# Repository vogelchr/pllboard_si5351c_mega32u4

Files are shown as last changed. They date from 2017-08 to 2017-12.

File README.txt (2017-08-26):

Si5351C PLL + ATmega32U4 PLL / OCXO-Control / Clock Generator

A PCB to provide a Si5351C clock generator IC with power via USB
and also have a ATmega32U4 control it.

The PLL chip can be provided two clocks:

 (1) standalone XTAL for Si5351C
      -> populate XT2

 (2a) external reference input (X8)
     (top right SMA connector when looking at top layer of PCB)

     -> Populate R18 (termination for SMA X8)
     -> Populate R27 (connects X8 with J3, Pin7)
     -> Populate R21, R22 (voltage divider to match Si5351C clkin voltage)

 (2b) quartz (TCXO, OCXO) oscillator connected to J3

     -> Populate R21, R22 (voltage divider to match Si5351C clkin voltage)
     -> A MCP47x6 DAC can be populated to provide a control voltage

If the clock (2a/2b) should be disciplined, this can be achieved
by having the ATmega32U4 determine the clock phase.

 (1) have a 1PPS input on the reference input (X8)

     -> Populate R17, R18 (termination, series resistor) for the
        atmega32u4 comparator input

     Then have the Si5351C output a suitable frequency to the atmega32u4
     on clock output 3, and...

     -> pouplate R25 to feed the external timer clock input T0,
        which has a maximum frequency of clkIO/2

          or

     -> populate R26, R20 and feed this frequency to the atmega32u4
        as the system clock. in this case, the otp memory of the
        Si5351C will have to be programmed so that it starts up
        with the clk3 active, and care must be taken not to turn
        off this clock, or the atmega32u4 will stop operating

     This way the ATmega32U4 can measure the clock phase of the 1PPS.

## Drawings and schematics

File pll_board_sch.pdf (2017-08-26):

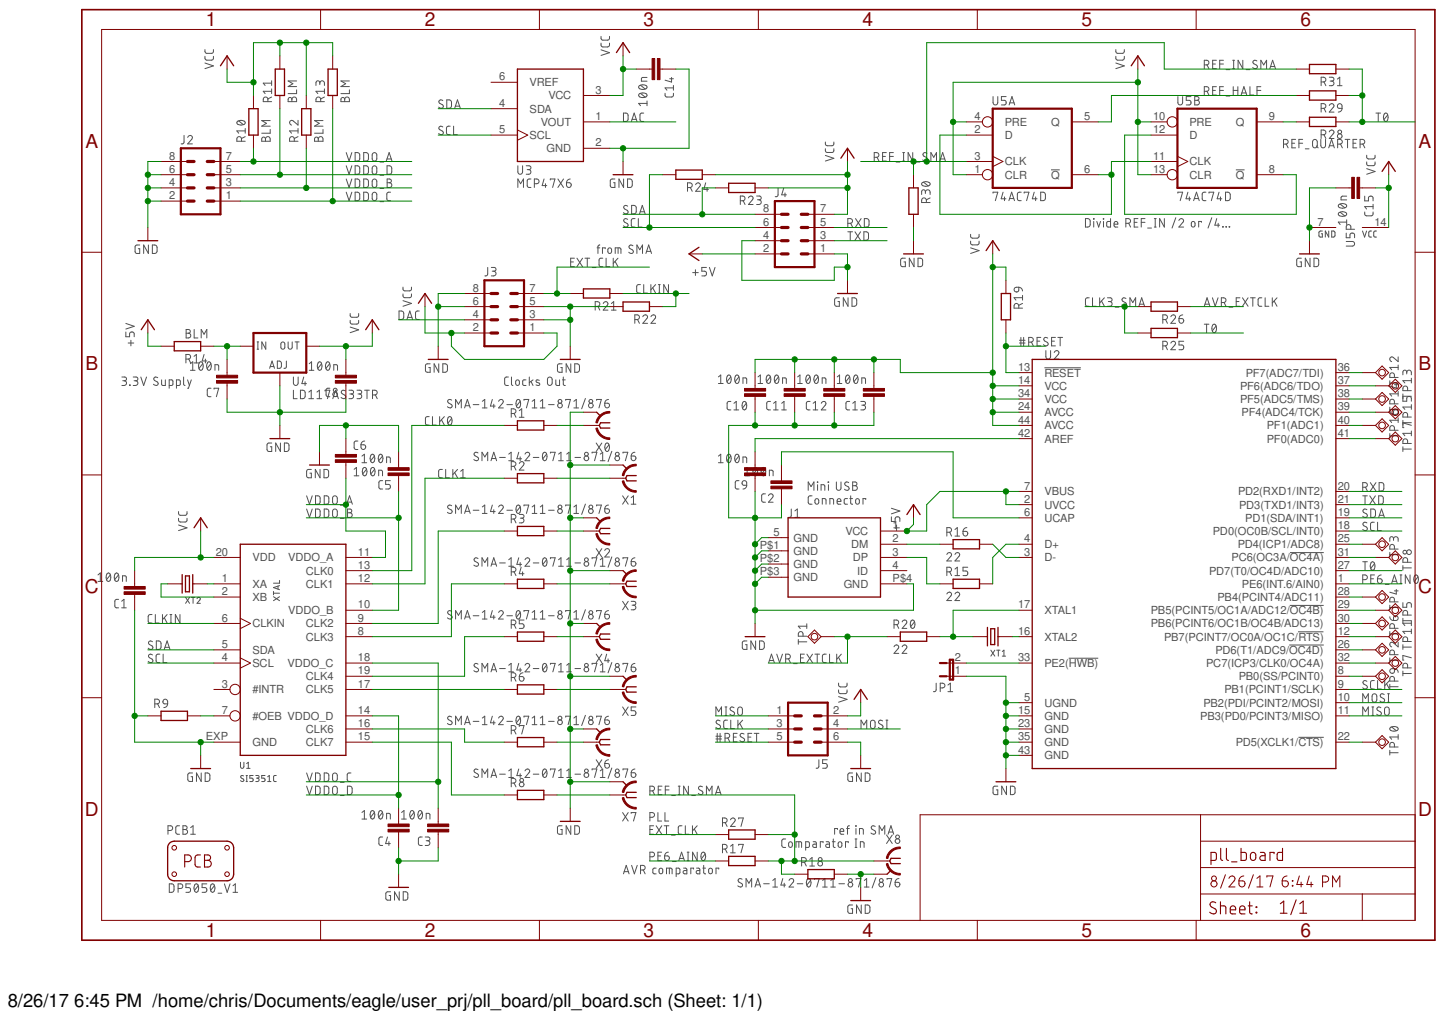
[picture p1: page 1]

8/26/17 6:45 PM /home/chris/Documents/eagle/user_prj/pll_board/pll_board.sch (Sheet: 1/1)

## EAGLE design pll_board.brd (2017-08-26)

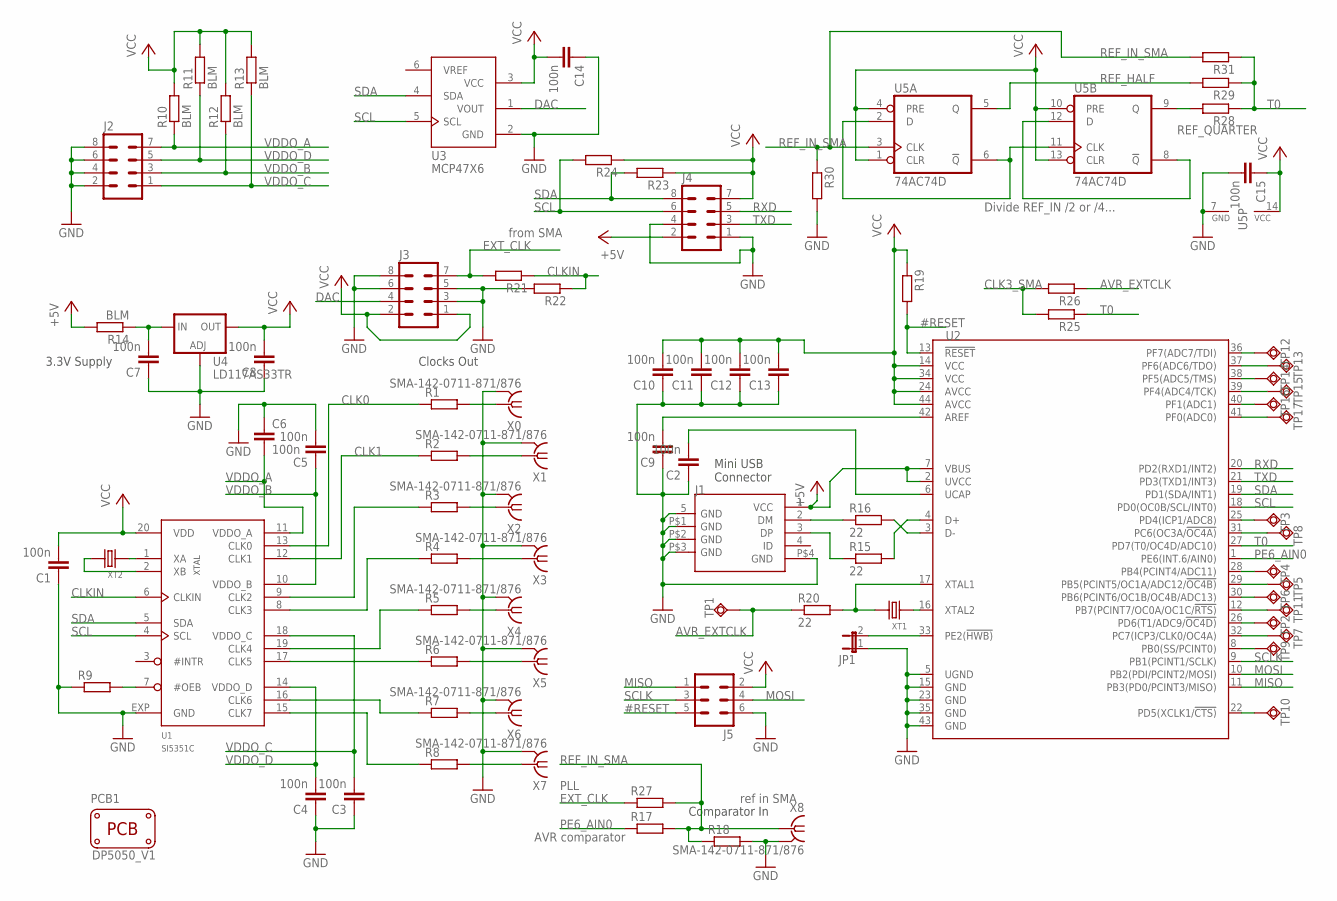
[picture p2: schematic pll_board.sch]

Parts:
C1, C2, C3, C4, C5, C6, C7, C8, C9, C10, C11, C12, C13, C14, C15: 100n; C0805
J1: MINI-USB-RCPT-B-5PS-R/A-SMD(ST-USB-002A); MINIUSB5+4P-SMD-0.8-90D
J2, J3, J4: MA04-2
J5: MA03-2
JP1: JP1E; JP1
PCB1: PCB_DP_SQUARE-5X5; DP5050_V1
R1, R2, R3, R4, R5, R6, R7, R8, R9, R17, R18, R19, R21, R22, R23, R24, R25, R26, R27, R28, R29, R30, R31: R-EU_R0805; R0805
R10, R11, R12, R13, R14: BLM; R0805
R15, R16, R20: 22; R0805
TP1, TP2, TP3, TP4, TP5, TP6, TP7, TP8, TP9, TP10, TP11, TP12, TP13, TP14, TP15, TP16, TP17: TPSQB1,27; B1,27
U1: SI5351C; QFN20
U2: MCU-ATMEGA32U4(TQFP44)-AU; TQFP44-0.8-9.6X9.6MM
U3: MCP47X6; SOT23-6
U4: LD117AS33TR; SOT223
U5: 74AC74D; SO14
X0, X1, X2, X3, X4, X5, X6, X7, X8: SMA-142-0711-871/876; J502-ND-142-0711-871/876
XT1, XT2: CRYSTAL'3225'; X4-SMD-3.2X2.5X0.7MM

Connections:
#OEB: R9.2, U1.7 (#OEB)
#RESET: J5.5, R19.2, U2.13 (!RESET)
+5V: J1.1 (VCC), J4.2, R14.2, U2.2 (UVCC), U2.7 (VBUS)
AREF: C9.2, U2.42 (AREF)
AVR_EXTCLK: R20.1, R26.1, TP1.TP
CLK0: R1.1, U1.13 (CLK0)
CLK0_SMA: R1.2, X0.1
CLK1: R2.1, U1.12 (CLK1)
CLK1_SMA: R2.2, X1.1
CLK2: R3.1, U1.9 (CLK2)
CLK2_SMA: R3.2, X2.1
CLK3: R4.1, U1.8 (CLK3)
CLK3_SMA: R4.2, R25.2, R26.2, X3.1
CLK4: R5.1, U1.19 (CLK4)
CLK4_SMA: R5.2, X4.1
CLK5: R6.1, U1.17 (CLK5)
CLK5_SMA: R6.2, X5.1
CLK6: R7.1, U1.16 (CLK6)
CLK6_SMA: R7.2, X6.1
CLK7: R8.1, U1.15 (CLK7)
CLK7_SMA: R8.2, X7.1
CLKIN: R21.1, R22.1, U1.6 (CLKIN)
DAC: J3.4, U3.1 (VOUT)
EXT_CLK: J3.7, R21.2, R27.1
GND: C1.1, C2.1, C3.1, C4.1, C5.2, C6.1, C7.1, C8.1, C9.1, C10.1, C11.1, C12.1, C13.1, C14.1, C15.2, J1.5 (GND), J1.P$1 (GND), J1.P$2 (GND), J1.P$3 (GND), J1.P$4 (GND), J2.2, J2.4, J2.6, J2.8, J3.3, J3.5, J3.6, J3.8, J4.1, J4.4, J5.6, JP1.1, R9.1, R18.2, R22.2, R30.2, U1.EXP (GND), U2.5 (UGND), U2.15 (GND), U2.23 (GND), U2.35 (GND), U2.43 (GND), U3.2 (GND), U4.1 (ADJ), U5.7 (GND), X0.G@1 (2), X0.G@2 (2), X0.G@3 (2), X0.G@4 (2), X1.G@1 (2), X1.G@2 (2), X1.G@3 (2), X1.G@4 (2), X2.G@1 (2), X2.G@2 (2), X2.G@3 (2), X2.G@4 (2), X3.G@1 (2), X3.G@2 (2), X3.G@3 (2), X3.G@4 (2), X4.G@1 (2), X4.G@2 (2), X4.G@3 (2), X4.G@4 (2), X5.G@1 (2), X5.G@2 (2), X5.G@3 (2), X5.G@4 (2), X6.G@1 (2), X6.G@2 (2), X6.G@3 (2), X6.G@4 (2), X7.G@1 (2), X7.G@2 (2), X7.G@3 (2), X7.G@4 (2), X8.G@1 (2), X8.G@2 (2), X8.G@3 (2), X8.G@4 (2)
LDO_IN: C7.2, R14.1, U4.3 (IN)
MISO: J5.1, U2.11 (PB3(PD0/PCINT3/MISO))
MOSI: J5.4, U2.10 (PB2(PDI/PCINT2/MOSI))
unnamed: U2.16 (XTAL2), XT1.2 (1)
unnamed: U1.1 (XA), XT2.2 (1)
unnamed: R20.2, U2.17 (XTAL1), XT1.4 (2)
unnamed: JP1.2, U2.33 (PE2(!HWB))
unnamed: U1.2 (XB), XT2.4 (2)
P8: TP9.TP, U2.8 (PB0(SS/PCINT0))
P12: TP11.TP, U2.12 (PB7(PCINT7/OC0A/OC1C/!RTS))
P22: TP10.TP, U2.22 (PD5(XCLK1/!CTS))
P25: TP3.TP, U2.25 (PD4(ICP1/ADC8))
P26: TP2.TP, U2.26 (PD6(T1/ADC9/!OC4D))
P28: TP4.TP, U2.28 (PB4(PCINT4/ADC11))
P29: TP5.TP, U2.29 (PB5(PCINT5/OC1A/ADC12/!OC4B))
P30: TP6.TP, U2.30 (PB6(PCINT6/OC1B/OC4B/ADC13))
P31: TP8.TP, U2.31 (PC6(OC3A/!OC4A))
P32: TP7.TP, U2.32 (PC7(ICP3/CLK0/OC4A))
P36: TP12.TP, U2.36 (PF7(ADC7/TDI))
P37: TP13.TP, U2.37 (PF6(ADC6/TDO))
P38: TP14.TP, U2.38 (PF5(ADC5/TMS))
P39: TP15.TP, U2.39 (PF4(ADC4/TCK))
P40: TP16.TP, U2.40 (PF1(ADC1))
P41: TP17.TP, U2.41 (PF0(ADC0))
PE6_AIN0: R17.1, U2.1 (PE6(INT.6/AIN0))
REF_HALF: R29.2, U5.5 (Q)
REF_HALF_N: U5.2 (D), U5.6 (!Q), U5.11 (CLK)
REF_IN_SMA: R17.2, R18.1, R27.2, R30.1, R31.2, U5.3 (CLK), X8.1
REF_QUARTER: R28.2, U5.9 (Q)
REF_QUARTER_N: U5.8 (!Q), U5.12 (D)
RXD: J4.5, U2.20 (PD2(RXD1/INT2))
SCL: J4.6, R24.2, U1.4 (SCL), U2.18 (PD0(OC0B/SCL/INT0)), U3.5 (SCL)
SCLK: J5.3, U2.9 (PB1(PCINT1/SCLK))
SDA: J4.8, R23.2, U1.5 (SDA), U2.19 (PD1(SDA/INT1)), U3.4 (SDA)
T0: R25.1, R28.1, R29.1, R31.1, U2.27 (PD7(T0/OC4D/ADC10))
TXD: J4.3, U2.21 (PD3(TXD1/INT3))
UCAP: C2.2, U2.6 (UCAP)
USBD_CON_N: J1.2 (DM), R16.1
USBD_CON_P: J1.3 (DP), R15.1
USBD_N: R16.2, U2.3 (D-)
USBD_P: R15.2, U2.4 (D+)
VCC: C1.2, C8.2, C10.2, C11.2, C12.2, C13.2, C14.2, C15.1, J3.1, J3.2, J4.7, J5.2, R10.2, R11.2, R12.2, R13.2, R19.1, R23.1, R24.1, U1.20 (VDD), U2.14 (VCC), U2.24 (AVCC), U2.34 (VCC), U2.44 (AVCC), U3.3 (VCC), U4.4 (OUT), U5.1 (CLR), U5.4 (PRE), U5.10 (PRE), U5.13 (CLR), U5.14 (VCC)
VDDO_A: C6.2, J2.7, R10.1, U1.11 (VDDO_A)
VDDO_B: C5.1, J2.3, R12.1, U1.10 (VDDO_B)
VDDO_C: C3.2, J2.1, R13.1, U1.18 (VDDO_C)
VDDO_D: C4.2, J2.5, R11.1, U1.14 (VDDO_D)

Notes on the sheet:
Comparator In
Clocks Out
3.3V Supply
Mini USB Connector
from SMA
ref in SMA
AVR comparator
PLL
Divide REF_IN /2 or /4...

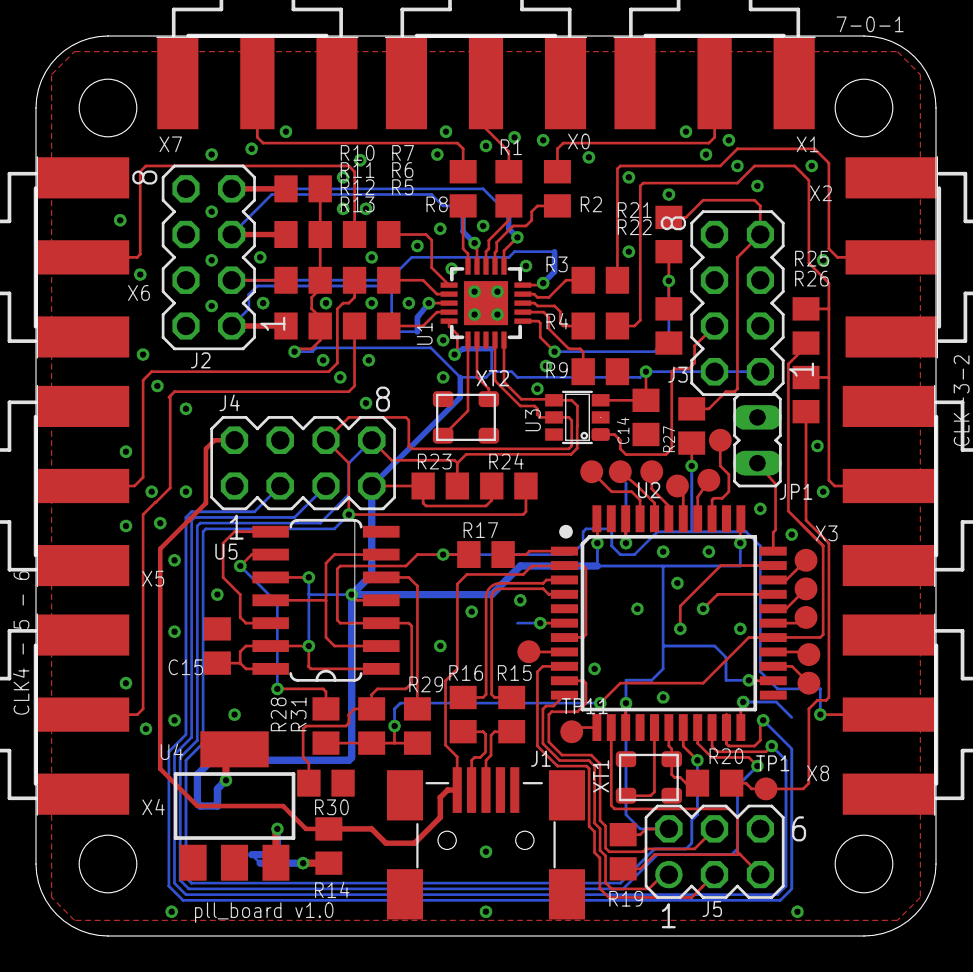
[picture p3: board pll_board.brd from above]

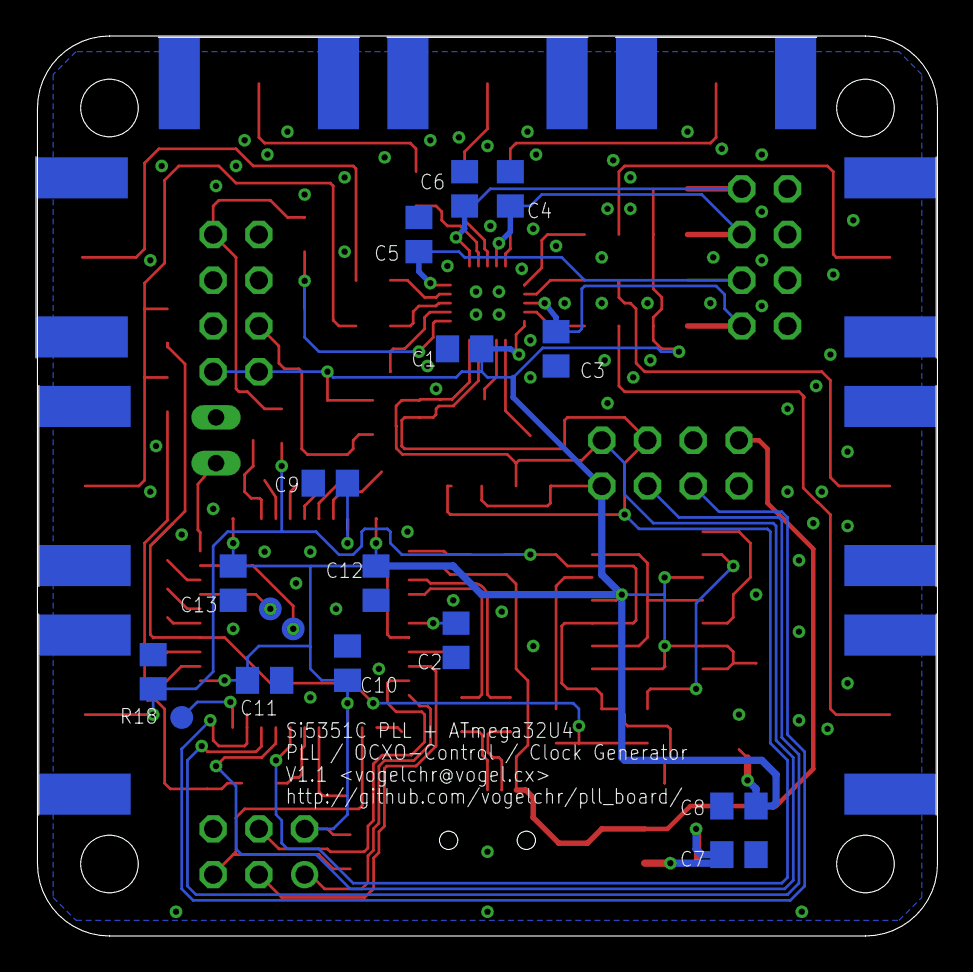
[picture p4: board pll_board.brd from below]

Board: 2 copper layers, 50.0 x 50.0 mm, 86 parts (17 on the bottom side), 71 nets.

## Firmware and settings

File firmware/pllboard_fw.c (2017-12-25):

/*
Copyright 2014  Christian Vogel <vogelchr@vogel.cx>

Copyright 2013  Dean Camera (dean [at] fourwalledcubicle [dot] com)

Based on the "VirtualSerial" demo, to be found in the
LUFA (Lightweight USB Framework for AVRs) library.
http://www.fourwalledcubicle.com/LUFA.php
*/

#include "avr_i2c_master.h"
#include "cmdline.h"
#include "default_pll_config.h"

#include <avr/io.h>
#include <avr/wdt.h>
#include <avr/power.h>
#include <avr/interrupt.h>
#include <avr/pgmspace.h>
#include <string.h>
#include <stdio.h>

#include "vserial-descriptors.h"

#include <LUFA/Drivers/USB/USB.h>
#include <LUFA/Platform/Platform.h>

void SetupHardware(void);

void EVENT_USB_Device_Connect(void);
void EVENT_USB_Device_Disconnect(void);
void EVENT_USB_Device_ConfigurationChanged(void);
void EVENT_USB_Device_ControlRequest(void);

/*
 * LUFA CDC Class driver interface configuration and state information. This
 * structure is  passed to all CDC Class driver functions, so that multiple
 * instances of the same class  within a device can be differentiated from one
 * another.
 */

USB_ClassInfo_CDC_Device_t VirtualSerial_CDC_Interface = {
	.Config = {
		.ControlInterfaceNumber   = 0,
		.DataINEndpoint           = {
			.Address          = CDC_TX_EPADDR,
			.Size             = CDC_TXRX_EPSIZE,
			.Banks            = 1,
		},
		.DataOUTEndpoint = {
			.Address          = CDC_RX_EPADDR,
			.Size             = CDC_TXRX_EPSIZE,
			.Banks            = 1,
		},
		.NotificationEndpoint = {
			.Address          = CDC_NOTIFICATION_EPADDR,
			.Size             = CDC_NOTIFICATION_EPSIZE,
			.Banks            = 1,
		},
	},
};

int main(void)
{
	SetupHardware();
	int16_t i;

	/*
	 * Create a regular character stream for the interface so that it can
	 * be used with the stdio.h functions
	 */
	CDC_Device_CreateStream(&VirtualSerial_CDC_Interface, &cmdline_out_stream);

	GlobalInterruptEnable();


	DDRF |= _BV(0) | _BV(1);

	for (;;)
	{
		CDC_Device_USBTask(&VirtualSerial_CDC_Interface);
		USB_USBTask();
		/*
		 * Must throw away unused bytes from the host, or it will
		 * lock up while waiting for the device
		 */
		i = CDC_Device_ReceiveByte(&VirtualSerial_CDC_Interface);
		if (i == -1) {
			cmdline_tick();
			continue;
		}
		cmdline_eat_char(i);
	}
}

/*
 * Configures the board hardware and chip peripherals
 * for the demo's functionality.
 */
void SetupHardware(void)
{
	int i;

	/* Disable watchdog if enabled by bootloader/fuses */
	MCUSR &= ~(1 << WDRF);
	wdt_disable();

	/* Disable clock division */
	clock_prescale_set(clock_div_1);

	avr_i2c_master_init();
	for (i=0; i<si5351c_default_config_nelems; i++) {
		avr_i2c_master_buf[0] = AVR_I2C_MASTER_ADDR_WRITE(0x60);
		avr_i2c_master_buf[1] = pgm_read_byte(&si5351c_default_config[i].addr);
		avr_i2c_master_buf[2] = pgm_read_byte(&si5351c_default_config[i].val);
		avr_i2c_master_buflen = 3;
		avr_i2c_master_trigger(AVR_I2C_MASTER_XFER_STOP);

		while (avr_i2c_master_get_flags() & AVR_I2C_MASTER_RUNNING);
	}


	/* Hardware Initialization */
	USB_Init();



}

/** Event handler for the library USB Connection event. */
void EVENT_USB_Device_Connect(void)
{
	/* ... */
}

/* Event handler for the library USB Disconnection event. */
void EVENT_USB_Device_Disconnect(void)
{
	/* ... */
}

/** Event handler for the library USB Configuration Changed event. */
void EVENT_USB_Device_ConfigurationChanged(void)
{
	bool ConfigSuccess = true;

	ConfigSuccess &= CDC_Device_ConfigureEndpoints(&VirtualSerial_CDC_Interface);
}

/* Event handler for the library USB Control Request reception event. */
void EVENT_USB_Device_ControlRequest(void)
{
	CDC_Device_ProcessControlRequest(&VirtualSerial_CDC_Interface);
}

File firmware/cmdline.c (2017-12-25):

#include "cmdline.h"
#include "avr_i2c_master.h"
#include <avr/pgmspace.h>

FILE cmdline_out_stream;
FILE *pout = &cmdline_out_stream;

static unsigned char cmdline_buf[32];
static unsigned char cmdline_len;

/* as a response to read/write commands */
enum cmdline_wait_usb {
	WAIT_USB_NONE,
	WAIT_USB_READ,
	WAIT_USB_WRITE
};

uint8_t dump_si5351c_active;
uint8_t dump_si5351c_offs;

enum cmdline_wait_usb cmdline_wait_usb;

static uint8_t nibble(char c)
{
	if (c >= '0' && c <= '9')
		return c - '0';
	if (c >= 'a' && c <= 'f')
		return c - ('a' + 10);
	if (c >= 'A' && c <= 'F')
		return c - ('A' + 10);
	return 0;
}

static char to_hex(uint8_t c) {
	if (c < 10)
		return '0' + c;
	return 'a' + (c-10);
}

void
cmdline_parse(void)
{
	uint8_t i2c_addr, i2c_reg;
	uint8_t i;

	if (cmdline_len == 0)
		return;

	if (cmdline_len == 1 && cmdline_buf[0]=='?') {
		fprintf_P(pout,PSTR(
			"?         this help\r\n"
			"rAARR     start i2c register read from addr AA register #RR\r\n"
			"R         show i2c register read result\r\n"
			"wAARRVV.. write i2c register, values VV..\r\n"
			"i         show i2c debug flags\r\n"
			"d         dump si5351c registers\r\n"
			"X         reset i2c master logic\r\n"));
		return;
	}

	if (cmdline_len == 5 && cmdline_buf[0]=='r') {
		i2c_addr = (nibble(cmdline_buf[1])<<4) | nibble(cmdline_buf[2]);
		i2c_reg  = (nibble(cmdline_buf[3])<<4) | nibble(cmdline_buf[4]);
		fprintf_P(pout,PSTR("i2c read dev=0x%02x reg=0x%02x\n"),
			i2c_addr, i2c_reg);
		avr_i2c_master_buf[0] = AVR_I2C_MASTER_ADDR_WRITE(i2c_addr);
		avr_i2c_master_buf[1] = i2c_reg;
		avr_i2c_master_buflen = 2; /* 3 bytes in total are used */
		avr_i2c_master_trigger(AVR_I2C_MASTER_XFER_AUTORD);
		cmdline_wait_usb = WAIT_USB_READ;
		return;
	}

	if (cmdline_len >= 7 && cmdline_buf[0]=='w') {
		i2c_addr = (nibble(cmdline_buf[1])<<4) | nibble(cmdline_buf[2]);
		i2c_reg  = (nibble(cmdline_buf[3])<<4) | nibble(cmdline_buf[4]);

		for (i=0; i<(AVR_I2C_MASTER_MAX_BUFLEN-2); i++) {
			if (6+2*i >= cmdline_len) {
				fputc('@', pout);
				break;
			}
			fputc('.', pout);
			avr_i2c_master_buf[i+2] =
				(nibble(cmdline_buf[5+2*i]) << 4) |
				 nibble(cmdline_buf[6+2*i]);
		}

		fprintf_P(pout,
			PSTR("i2c write dev=0x%02x reg=0x%02x 0x%02x byte(s) payload\r\n"),
			i2c_addr, i2c_reg, i);

		avr_i2c_master_buf[0] = AVR_I2C_MASTER_ADDR_WRITE(i2c_addr);
		avr_i2c_master_buf[1] = i2c_reg;
		avr_i2c_master_buflen = i+2;

		avr_i2c_master_trigger(AVR_I2C_MASTER_XFER_STOP);
		cmdline_wait_usb = WAIT_USB_WRITE;
		return;
	}

	if (cmdline_len == 1 && cmdline_buf[0] == 'i') {
		fprintf_P(pout,
			PSTR("i2c status 0x%02x flags 0x%02x buflen 0x%02x\r\n"),
			avr_i2c_master_last_twsr,
			avr_i2c_master_get_flags(),
			avr_i2c_master_buflen);
		for (i=0; i<avr_i2c_master_buflen; i++) {
			uint8_t v = avr_i2c_master_buf[i];
			fputc(to_hex(v >> 4), pout);
			fputc(to_hex(v & 0x0f), pout);
		}
		fputc('\r', pout);
		fputc('\n', pout);
		return;
	}

	if (cmdline_len == 1 && cmdline_buf[0] == 'd') {
		avr_i2c_master_buf[0] = AVR_I2C_MASTER_ADDR_WRITE(0x60);
		avr_i2c_master_buf[1] = 0x00;
		avr_i2c_master_buflen = 17;
		avr_i2c_master_trigger(AVR_I2C_MASTER_XFER_AUTORD);
		dump_si5351c_active=1;
		dump_si5351c_offs=0;
		return;
	}

	if (cmdline_len == 1 && cmdline_buf[0] == 'X') {
		fprintf_P(pout,	PSTR("i2c master init\r\n"));
		avr_i2c_master_init();
		return;
	}

	fprintf_P(pout,	PSTR("unknown command \""));
	fwrite(cmdline_buf, cmdline_len, 1, pout);
	fprintf_P(pout, PSTR("\", try ? for help\r\n"));
}

void
cmdline_eat_char(unsigned char c)
{
	if (c == 0x7f || c == 0x08) {
		if (cmdline_len > 0) {
			cmdline_len--;
			/* left, space, left */
			fprintf_P(pout,PSTR("\033[D \033[D"));
		}
	}
	if (c>=32 && c<0x7f) {
		if (cmdline_len < sizeof(cmdline_buf)) {
			cmdline_buf[cmdline_len++] = c;
			fputc(c,pout);
		}
	}
	if (c == '\r' || c == '\f') {
		fputc('\r', pout);
		fputc('\n', pout);
		if (c == '\r')
			cmdline_parse();
		cmdline_len = 0;
		fprintf_P(pout,PSTR("\r\n>"));
	}
}

void
cmdline_tick()
{
	uint32_t flags;
	int i;

	flags = avr_i2c_master_get_flags();


	if (dump_si5351c_active) {
		if (flags & AVR_I2C_MASTER_RUNNING)
			return;
		if (flags == AVR_I2C_MASTER_IDLE) {
			fprintf_P(pout,PSTR("\r%02x:"), dump_si5351c_offs);
			for (i=1; i<avr_i2c_master_buflen; i++) {
				uint8_t v = avr_i2c_master_buf[i];
				fputc(to_hex(v >> 4), pout);
				fputc(to_hex(v & 0x0f), pout);
			}
			fputc('\r', pout);
			fputc('\n', pout);
			dump_si5351c_offs += 16;
			if (dump_si5351c_offs) { /* no overrun to zero! */
				avr_i2c_master_buf[0] = AVR_I2C_MASTER_ADDR_WRITE(0x60);
				avr_i2c_master_buf[1] = dump_si5351c_offs;
				avr_i2c_master_buflen = 17;
				avr_i2c_master_trigger(AVR_I2C_MASTER_XFER_AUTORD);
			} else {
				dump_si5351c_active=0;
			}
		}
		return;
	}

	if (cmdline_wait_usb != WAIT_USB_NONE) {
		if (!(flags & AVR_I2C_MASTER_RUNNING)) {
			fputc('\r', pout);
			fputc('\n', pout);

			if (flags & AVR_I2C_MASTER_ERR)
				fprintf_P(pout,
					PSTR("USB ERROR flags=%02x "), flags);
			else
				fprintf_P(pout,PSTR("USB:"));

			for (i=1; i<avr_i2c_master_buflen; i++) {
				uint8_t v = avr_i2c_master_buf[i];
				fputc(to_hex(v >> 4), pout);
				fputc(to_hex(v & 0x0f), pout);
			}

			fputc('\r', pout);
			fputc('\n', pout);
			fputc('>', pout);
			fwrite(cmdline_buf, cmdline_len, 1, pout);

			cmdline_wait_usb = WAIT_USB_NONE;
		}
		return;

	}
}

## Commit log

2017-08-26 Initial version.
    [pll_board.brd, pll_board.sch]
2017-08-26 Added PDF of schematics.
2017-08-26 Add USB +5V on i2c/uart connector.
    [pll_board.brd, pll_board.sch]
